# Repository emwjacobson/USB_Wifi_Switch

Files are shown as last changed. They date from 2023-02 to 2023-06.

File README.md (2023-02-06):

# USB Wifi Switch

This project aims to create a wifi-enabled module containing 2 individually switchable USB ports.

There are software-programmable LEDs that can be used to show the current status of each port.

## Schematics

The design is broken up into 2 parts, the MOSFET board and the Control board. In the assembled product, these are connected using headers to create a 2-layered design.

### Control Board

The control board consists of the ESP8266 module that controls the LEDs as well as the 2 MOSFETs on the MOSFET board.

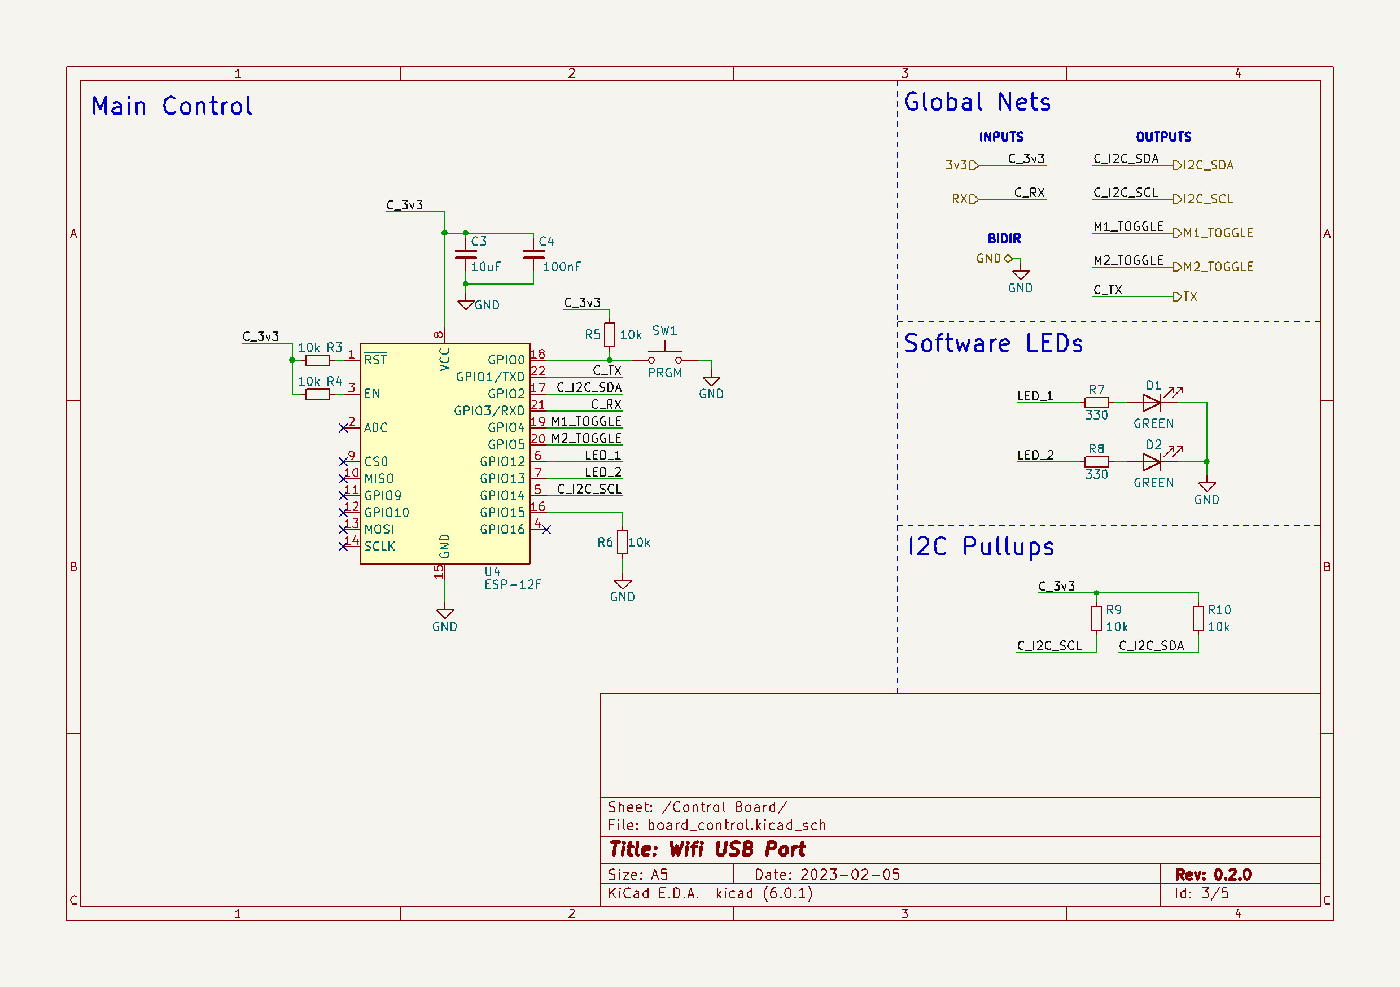
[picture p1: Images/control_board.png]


### MOSFET Board

As the name implies, this is the board that holds 2 copies of the power switching circuit as well as a 3.3v regular for the Control board.

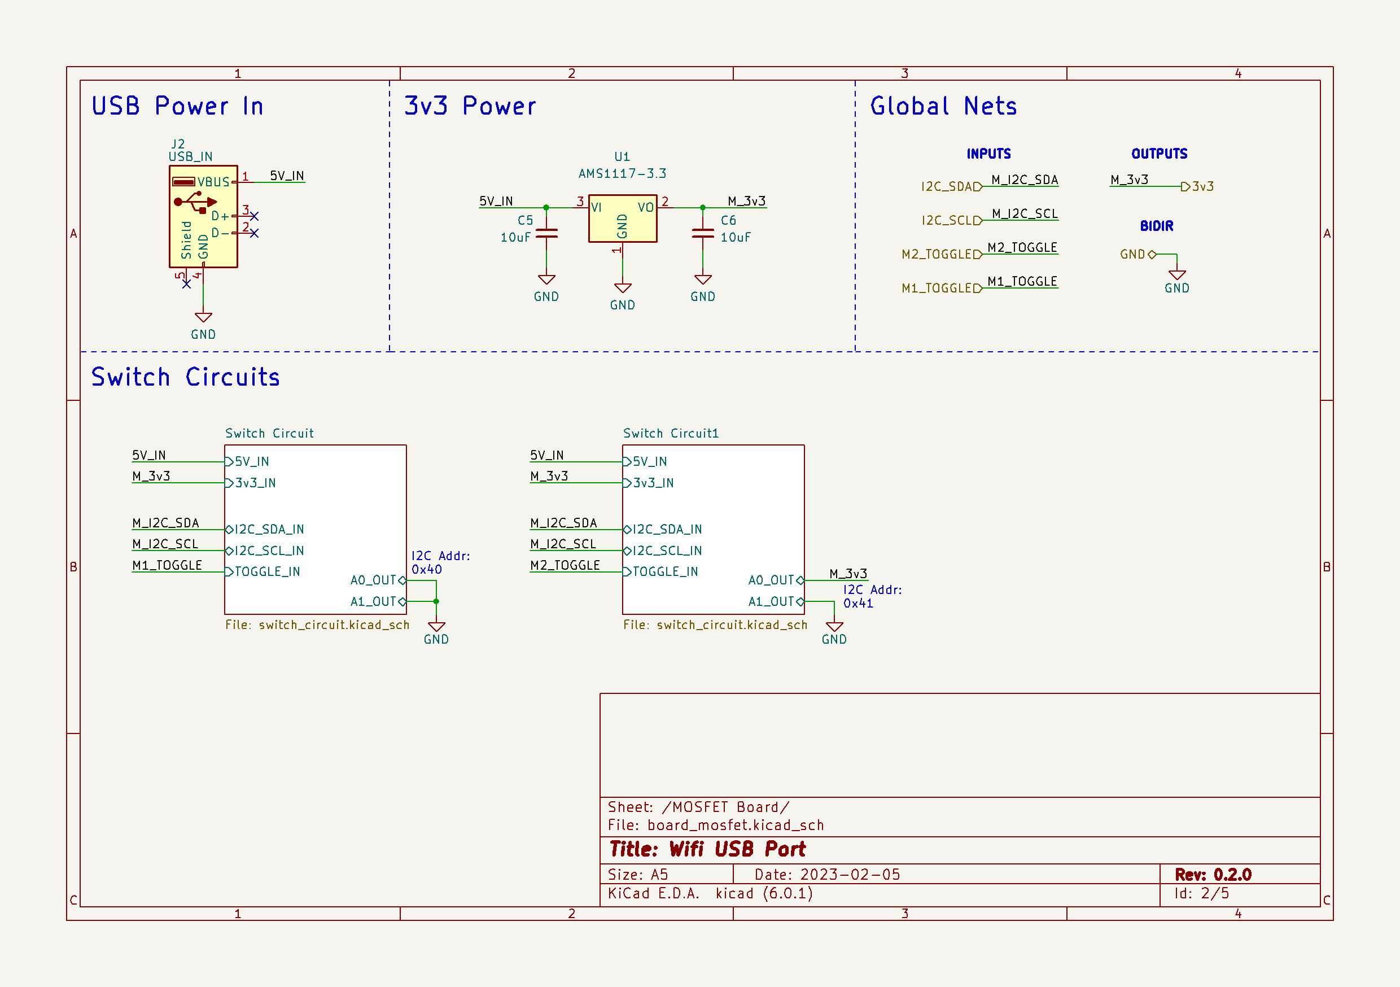
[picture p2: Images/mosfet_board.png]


### Switch Circuits

There are 2 copies of this circuit, as shown in the MOSFET Board schematic. The switch circuit contains

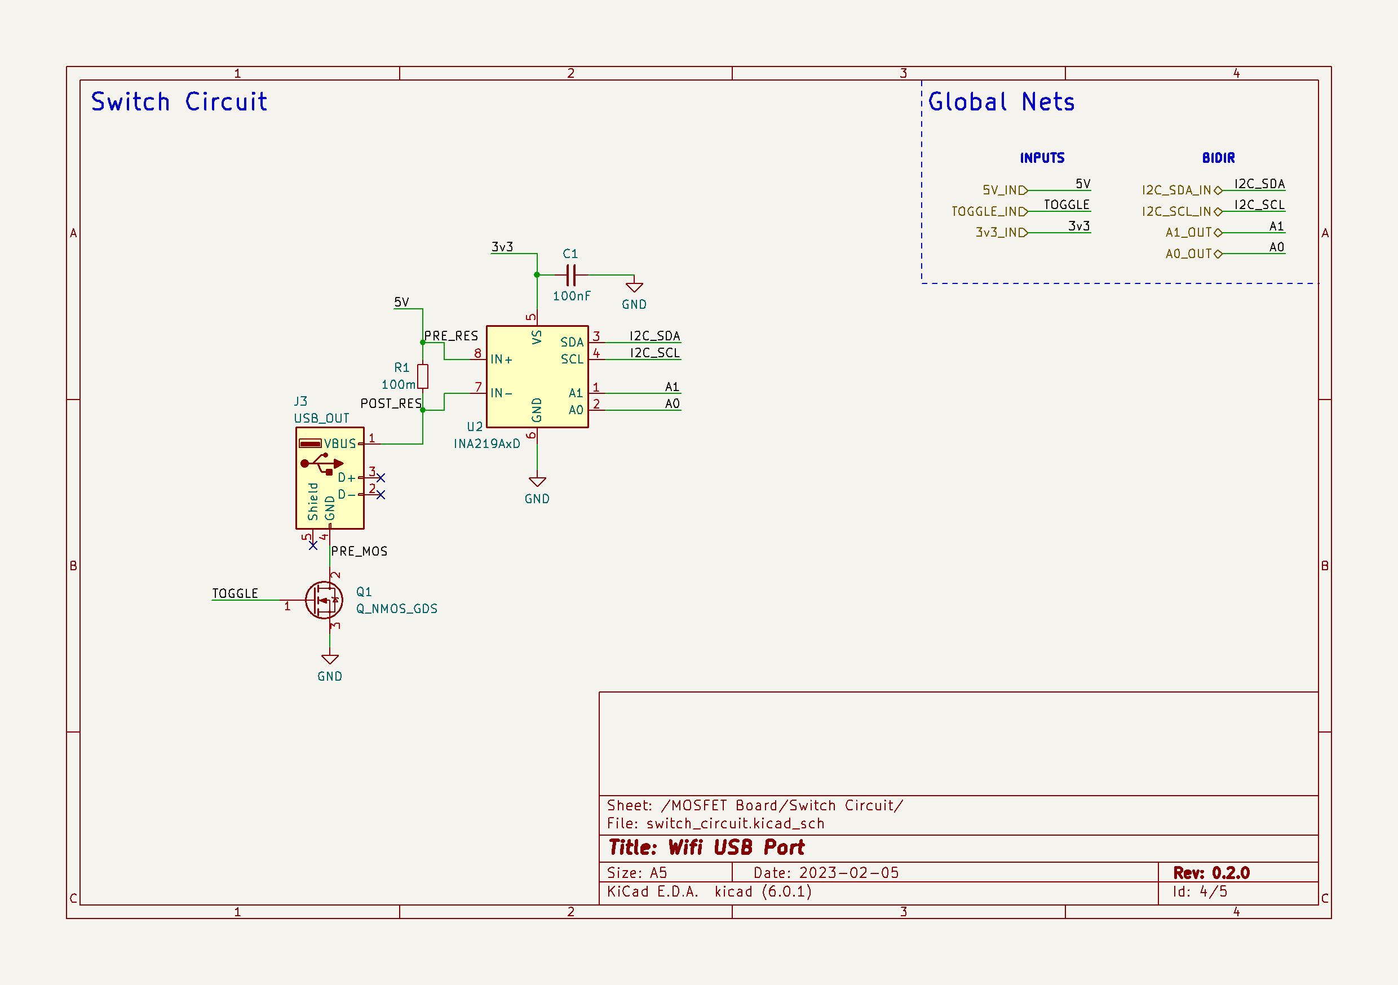
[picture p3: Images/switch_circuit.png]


## PCB

The PCB design was made as a single-sided component design, as it's easy enough for me to hand-assemble with a hot-air reflow station.

There is a v-score that is intended to be used to split the board into it's two halves and stacked with headers.

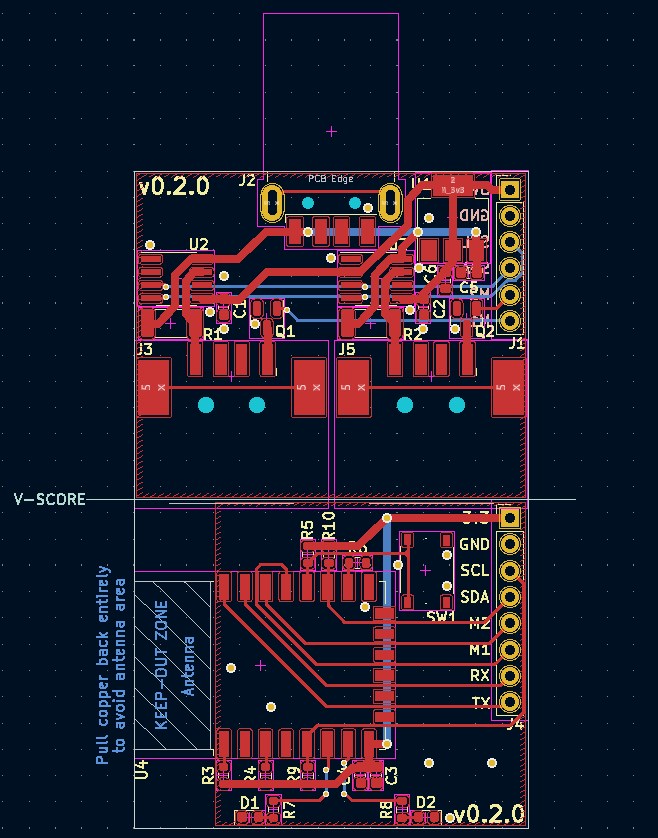
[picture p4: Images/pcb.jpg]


## Rendering

Currently I have an older version assembled and working on auto-charging a tablet I use as a Home Assistant dashboard. That board is v0.1.2, and does not have correct voltage reading. When I ver v0.2.0 ordered and assembled, I hope to post a photo of it.

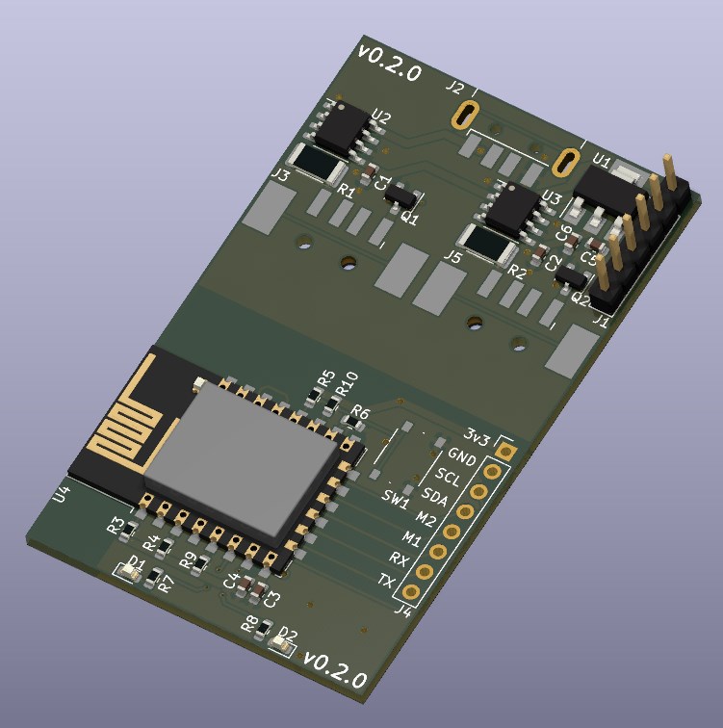
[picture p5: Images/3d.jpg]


I do have images of an even older version, v0.1, that I have since disassembled and reworked to be the v0.1.2 board that I currently use.

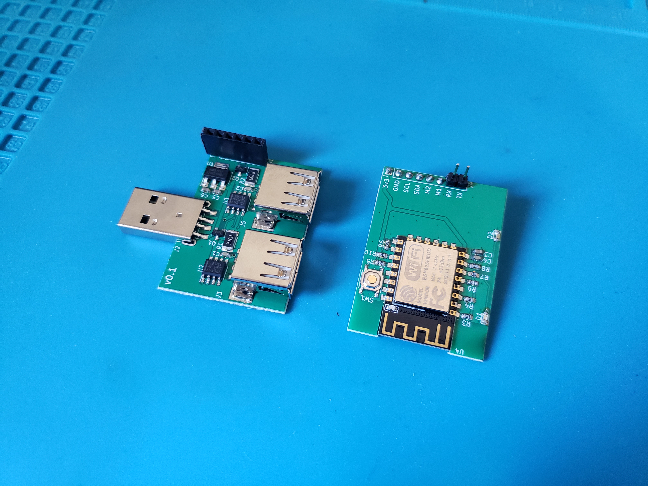
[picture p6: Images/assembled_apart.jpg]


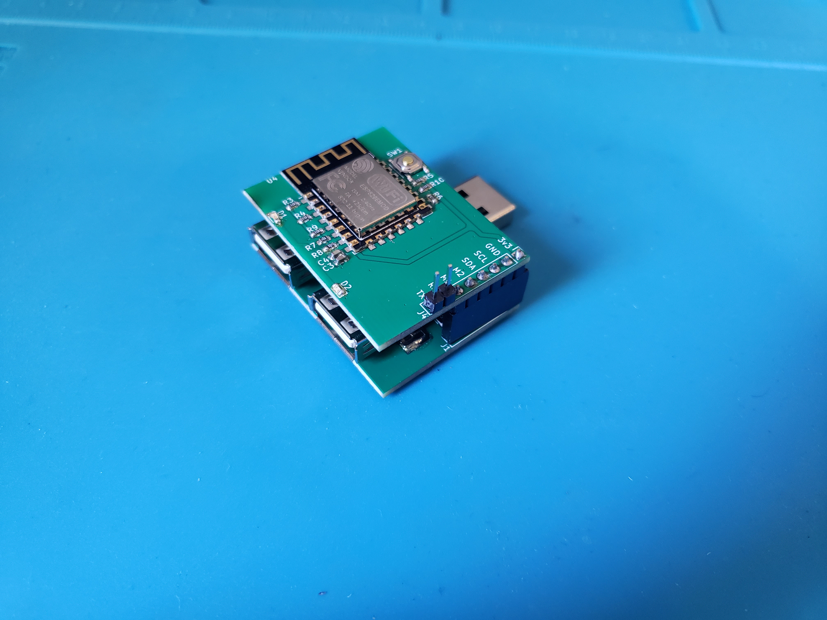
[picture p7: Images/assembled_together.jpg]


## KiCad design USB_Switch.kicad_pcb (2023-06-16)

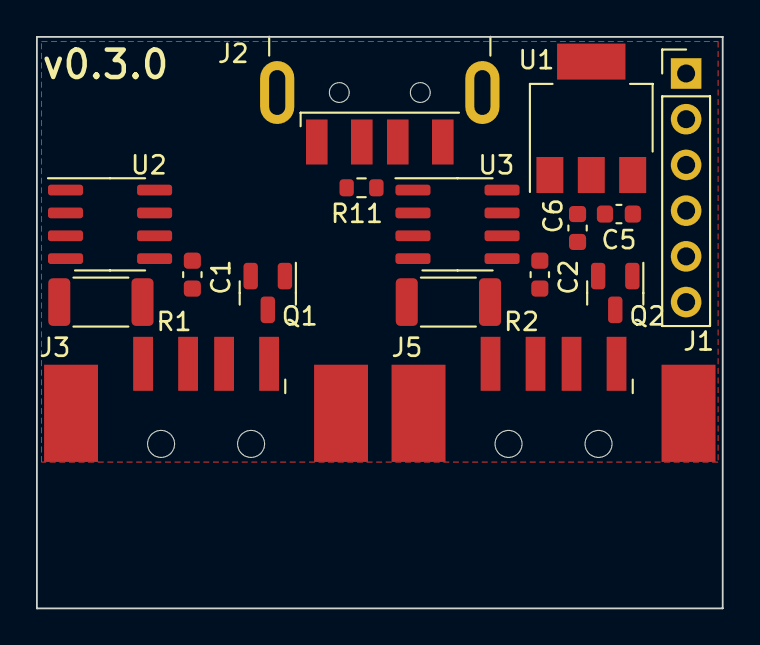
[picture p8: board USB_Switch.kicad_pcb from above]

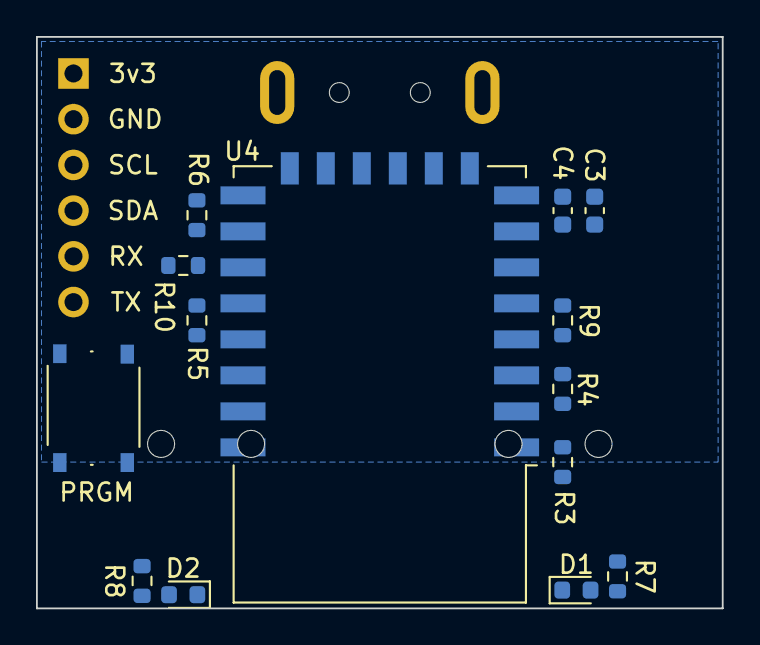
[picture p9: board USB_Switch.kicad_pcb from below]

Board: 2 copper layers, 38.1 x 31.8 mm, 30 parts (14 on the bottom side), 23 nets, no tracks yet.

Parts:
C1, C2, C4: 100nF; C_0603_1608Metric
C3, C5, C6: 10uF; C_0603_1608Metric
D1, D2: GREEN; LED_0603_1608Metric
J1: Conn_01x06; PinHeader_1x06_P2.54mm_Vertical
J2: USB_IN; U217-041N-4BV81
J3, J5: USB_OUT; 904-131A2032S10100
Q1, Q2: Q_NMOS_GDS; YJL3400A
R1, R2: 100m; R_2010_5025Metric
R3, R4, R5, R6, R9, R10: 10k; R_0603_1608Metric
R7, R8: 330; R_0603_1608Metric
R11: 100; R_0603_1608Metric
SW1: PRGM; TS-1187A-B-A-B
U1: AMS1117-3.3; SOT-223-3_TabPin2
U2, U3: INA219AxD; SOIC-8_3.9x4.9mm_P1.27mm
U4: ESP-12F; ESP-12E

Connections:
/3v3: C1.1, C2.1, C3.1, C4.1, C6.1, J1.1, R3.1, R4.1, R5.2, R9.1, R10.1, U1.2 (VO), U2.5 (VS), U3.2 (A0), U3.5 (VS), U4.8 (VCC)
/Control Board/LED_1: R7.1, U4.6 (GPIO12)
/Control Board/LED_2: R8.1, U4.7 (GPIO13)
/Control Board/M1_TOGGLE: Q1.1 (G), U4.19 (GPIO4)
/Control Board/M2_TOGGLE: Q2.1 (G), U4.20 (GPIO5)
/MOSFET Board/5V_IN: C5.1, J2.1 (VBUS), R1.1, R2.1, U1.3 (VI), U2.8 (IN+), U3.8 (IN+)
/MOSFET Board/Switch Circuit1/POST_RES: J5.1 (VBUS), R2.2, U3.7 (IN-)
/MOSFET Board/Switch Circuit1/PRE_MOS: J5.4 (GND), Q2.2 (D)
/MOSFET Board/Switch Circuit/POST_RES: J3.1 (VBUS), R1.2, U2.7 (IN-)
/MOSFET Board/Switch Circuit/PRE_MOS: J3.4 (GND), Q1.2 (D)
/RX: J1.5, U4.21 (GPIO3/RXD)
/SCL: J1.3, R9.2, U2.4 (SCL), U3.4 (SCL), U4.5 (GPIO14)
/SDA: J1.4, R10.2, U2.3 (SDA), U3.3 (SDA), U4.17 (GPIO2)
/TX: J1.6, U4.22 (GPIO1/TXD)
GND: C1.2, C2.2, C3.2, C4.2, C5.2, C6.2, D1.1 (K), D2.1 (K), J1.2, J2.4 (GND), Q1.3 (S), Q2.3 (S), R6.1, SW1.2, U1.1 (GND), U2.1 (A1), U2.2 (A0), U2.6 (GND), U3.1 (A1), U3.6 (GND), U4.15 (GND)
unnamed: D1.2 (A), R7.2
unnamed: D2.2 (A), R8.2
unnamed: J2.2 (D-), R11.2
unnamed: J2.3 (D+), R11.1
unnamed: R3.2, U4.1 (~RST)
unnamed: R4.2, U4.3 (EN)
unnamed: R5.1, SW1.1, U4.18 (GPIO0)
unnamed: R6.2, U4.16 (GPIO15)

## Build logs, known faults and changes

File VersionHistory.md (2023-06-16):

# Version History

Eventually I want to set something up on GitHub for proper versioning, but until then I'll keep track here.

## v0.1

I received the PCBs from JLCPCB on 11/14/22 and assembled them on 11/15. Programming the top had was easy enough using a "doner" NodeMCU that is piggybacked off of for programming.

When attempting to use the mosfet to switch power on to the output I realized that I used the mosfet in a p-channel arrangement while using an n-channel mosfet. Doh. This problem should be fixed in v0.1.1

## v0.1.1

This is the "patch" to fix the problem with the n-channel mosfet. Still has yet to be panelized and ordered, but the KiCAD project is correct.

## v0.1.2

Once I assembled v0.1.1, I realized that I had the wiring for the Female USB swapped! In addition, the pin labels for the mosfet still reflected the p-channel orientation, which caused them to be swapped as well.

## v0.2.0

Redesigned layout to be a bit more optimized, as well as put the power monitering IC on the correct side of the USB plug.

## v0.2.1

Added place for resistor between D+ and D-

## v0.3.0 Changes

### TODO

- USB ESD Protection
- Single PCB Design
  - ESP8266 on backside

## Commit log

2022-10-14 Initial commit, schematic started
    [USB _Switch.kicad_pcb, USB _Switch.kicad_sch]
2022-10-14 Split schematic into two sheets
    [USB _Switch.kicad_sch, board_control.kicad_sch, board_mosfet.kicad_sch]
2022-10-18 Fixed file name, started board layout
    [USB _Switch.kicad_pcb, USB_Switch.kicad_pcb, USB_Switch.kicad_sch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]
2022-10-19 Added capacitor filtering to AMS1117
    [USB_Switch.kicad_sch, board_mosfet.kicad_sch]
2022-10-19 Updated board connections. Added supplier info for all parts
    [USB_Switch.kicad_sch, board_control.kicad_sch, board_mosfet.kicad_sch]
2022-10-19 Did work on schematic
    [USB_Switch.kicad_pcb, USB_Switch.kicad_sch, board_control.kicad_sch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]
2022-10-20 Finished initial layout of PCB
    [USB_Switch.kicad_pcb, USB_Switch.kicad_sch, board_control.kicad_sch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]
2022-10-22 Added TX/RX to schematic. Updated PCB
    [USB_Switch.kicad_pcb, USB_Switch.kicad_sch, board_control.kicad_sch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]
2022-10-23 Updated PCB layout to have cleaner dimensions
    [USB_Switch.kicad_pcb]
2022-10-23 Moved v-score to User.drawing layer
    [USB_Switch.kicad_pcb]
2022-10-23 Fixed inversed naming on connectors
    [USB_Switch.kicad_pcb, USB_Switch.kicad_sch]
2022-10-23 Added more GND vias, fixed incorrect net trace sizing
    [USB_Switch.kicad_pcb, USB_Switch.kicad_sch, board_control.kicad_sch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]
2022-10-23 More GND via placements
    [USB_Switch.kicad_pcb]
2022-10-28 Fixed silkscreen placement
    [USB_Switch.kicad_pcb]
2022-10-28 Fixed grid origin
    [USB_Switch.kicad_pcb]
2022-10-29 Updated some components to use ones I already own
    [USB_Switch.kicad_pcb, USB_Switch.kicad_sch, board_control.kicad_sch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]
2022-11-16 Fixed error with mosfet arrangement.
    [USB_Switch.kicad_pcb, USB_Switch.kicad_sch, board_mosfet.kicad_sch]
2022-11-16 Moved vscore to User.ECO1 layer to avoid unintended cuts
    [USB_Switch.kicad_pcb]
2022-12-02 Updated footprints, fixed PCB layout
    [USB_Switch.kicad_pcb, USB_Switch.kicad_sch, board_mosfet.kicad_sch]
2022-12-02 Updated version number, added to second half of board
    [USB_Switch.kicad_pcb]
2023-02-06 Updated to v0.2.0
    [USB_Switch.kicad_pcb, USB_Switch.kicad_sch, board_mosfet.kicad_sch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]
2023-02-06 Made schematics pretty, added photos, added README
    [USB_Switch.kicad_pcb, USB_Switch.kicad_sch, board_control.kicad_sch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]
2023-02-07 Fixed area under antenna being filled with copper pour
    [USB_Switch.kicad_pcb]
2023-02-07 Removed rule zone, changed copper pour region
    [USB_Switch.kicad_pcb]
2023-02-08 Added note about copper pour on control board, added cutout on PCB behind antenna.
    [USB_Switch.kicad_pcb]
2023-03-12 Added resistor between D+ and D-
    [USB_Switch.kicad_pcb, USB_Switch.kicad_sch, board_control.kicad_sch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]
2023-06-15 Fixed version number on PCB
    [USB_Switch.kicad_pcb]
2023-06-16 Initial change moving items to back of PCB
    [USB_Switch.kicad_pcb, USB_Switch.kicad_sch, board_control.kicad_sch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]
